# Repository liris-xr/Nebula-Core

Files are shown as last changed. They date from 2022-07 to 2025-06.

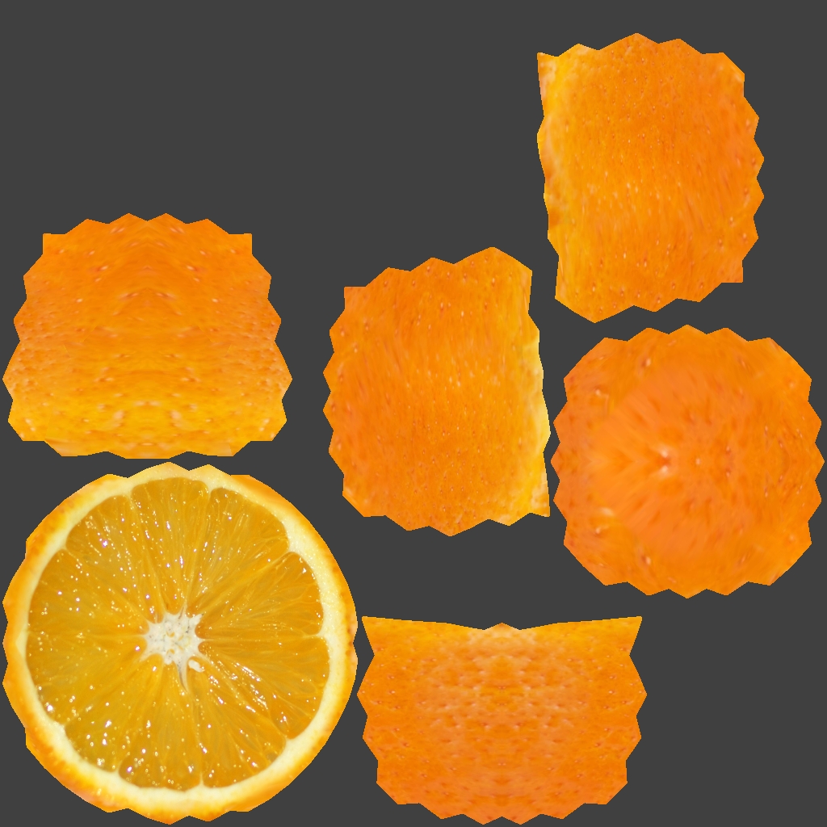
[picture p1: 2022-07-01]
Nebula-UnitySoftware/Assets/3D_Objects/Orange/orange_halb3DC_(null)_color.jpg

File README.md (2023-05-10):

nebula_banner

# Nebula: an affordable open-source and autonomous olfactory display for VR headsets

Charles JAVERLIAT, Pierre-Philippe ELST, Anne-Lise SAIVE, Patrick BAERT, Guillaume LAVOUE.

_Conference on Virtual Reality Software and Technology (VRST), 2022._

[[Paper]](https://hal.science/hal-03838757v1/file/Nebula_VRST_2022%20%281%29.pdf)

## Description 

The impact of olfactory cues on user experience in virtual reality is increasingly studied. However, results are still heterogeneous and existing studies are difficult to replicate, mainly due to a lack of standardized olfactory displays. In that context, we present Nebula, a **_low-cost_** (less than 100€), **_open-source_**, olfactory display capable of diffusing scents at *different diffusion rates* using a nebulization process. Nebula can be used with **PC VR** or **autonomous** head mounted displays, making it easily transportable without any external computer needed.

Nebula can be easily replicated using a 3D printers and some basic electronic skills. On this repo, you will find anything needed in order to build our proposed olfactory display. 

### How does it work?

Nebula create an odorant mist using an **ultrasonic atomizer**, powered by a *pulse width modulated signal* (PWM). As a result, increasing the duty cycle results in an increased rate of diffusion.
This modulation, handled by a micro-controller (we used an Arduino Nano Every) allows Nebula to reach several olfactory intensities.

In addition to the atomizer, we used two fans which are useful to control our air flow. The smallest one, *5VDC 25x25x6mm*, is always active and forces a constant air flow to be able to smell the odor more rapidly after its diffusion and mitigates the pressure drop when enabling the extraction fan. This one is a *12VDC 40x40x20mm*, much stronger, that runs for 2 seconds in order to extract the remaining odorant and thus improve the reactivity of the device.

Nebula is ready to be used with Unity (PC VR built or in editor), using the provided Unity-Package or scripts from the Nebula-UnitySoftware folder.
Furthemore, Nebula works standalone using an Android Archive Library using the provided package on your own built scene. (Tested on a Meta Quest 2)

  ## Repository Structure

  * [Nebula-CAD](https://github.com/Plateforme-VR-ENISE/Nebula-Core/tree/master/Nebula-CAD) contains all STL files (ready to print), a PDF version of the wiring diagram, a list of the necessary components and some printings recommendations.
  * [Nebula-Experiment](https://github.com/Plateforme-VR-ENISE/Nebula-Core/tree/master/Nebula-Experiment) contains results and the unity project used in our experiment described in our paper.
  * [Nebula-Firmware](https://github.com/Plateforme-VR-ENISE/Nebula-Core/tree/master/Nebula-Firmware) contains code for the microcontroller used (Arduino Nano Every).
  * [Nebula-UnitySoftware](https://github.com/Plateforme-VR-ENISE/Nebula-Core/tree/master/Nebula-UnitySoftware) is the Unity project using Nebula in VR including a sample scene with an orange ready to diffuse when approached to the nose !
  
   ## Release content
   
   * ``Nebula-UnityPackage`` Unity Package which includes everything needed to bring Nebula into your project unity. Includes Android Studio project for AAR files generation.
   * ``Nebula-PCSampleScene`` sample scene included in the repository built that countains a ready-to-use application for Nebula.
   * ``Nebula-SampleScene`` same as above but built for Meta Quest 2.

   ## How to install
   
  * Download the lastest ``Nebula.unitypackage`` on the [Release](https://github.com/Plateforme-VR-ENISE/Nebula-Core/releases) section.
  * Open your Unity project or create a new one.
  * Configure .NET 4.x API Compatibility Level **MANDATORY** on your project (*Edit => Project Settings => Player => Other Settings => Api Compatibility Level => .NET 4.x*).
  * Import ``Nebula.unitypackage`` previously downloaded (*Assets => Import Package => Custom Package*) and check *All => Import*.
  * Install OpenXR and XR Interaction Toolkit, you have to install them if you wants to use the provided sample scene (*Windows => Package Manager => Unity registery => Search for Open XR Plugin and XR Interaction Toolkit => Install*).
  * If needed : re-open the project.
   
   ## Contacts
   
   * Pierre-Philippe Elst (Engineer) : pierre-philippe.elst@enise.fr
   * Charles Javerliat (PhD Student) : charles.javerliat@enise.fr
   * Guillaume Lavoué (Professor) : guillaume.lavoue@enise.fr

## Citation

```
@inproceedings{javerliat2022,
  title = {Nebula: An Affordable Open-Source and Autonomous Olfactory Display for VR Headsets},
  author = {JAVERLIAT, Charles and Elst, Pierre-Philippe and Saive, Anne-Lise and Baert, Patrick and Lavou{\'e}, Guillaume},
  booktitle = {Proceedings of the 28th ACM Symposium on Virtual Reality Software and Technology},
  year = {2022},
  month = Nov,
  doi = {10.1145/3562939.3565617},
}
```

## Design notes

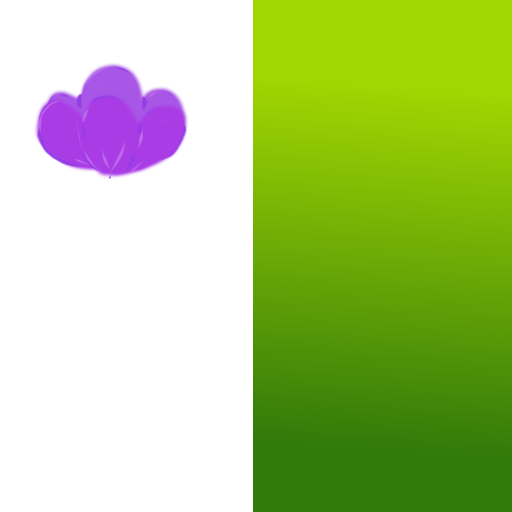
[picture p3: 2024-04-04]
Nebula-UnitySoftware/Assets/3D_Objects/Lavender/plant_lavender_tex.png

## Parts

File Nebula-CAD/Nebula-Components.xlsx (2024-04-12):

Name | Qty | ref | Estimated price - VAT included (€)
Arduino nano every | 1 | ABX00033 | 14
Seed studio - Atomizer | 2 | 101020090 | 22
Sunon - Extraction fan | 1 | MF40100V2-1000U-A99 | 10 | Another option (noiseless) : Noctua NF-A4x10 5V
Sunon - Input fan | 1 | MF25060V2-1000U-A99 | 6
Coton for aroma diffuser diameter 8mm | 1 |  | 8
Transistor NPN | 1 | BD139 | 1
 |  | Total estimated price for Nebula | 61

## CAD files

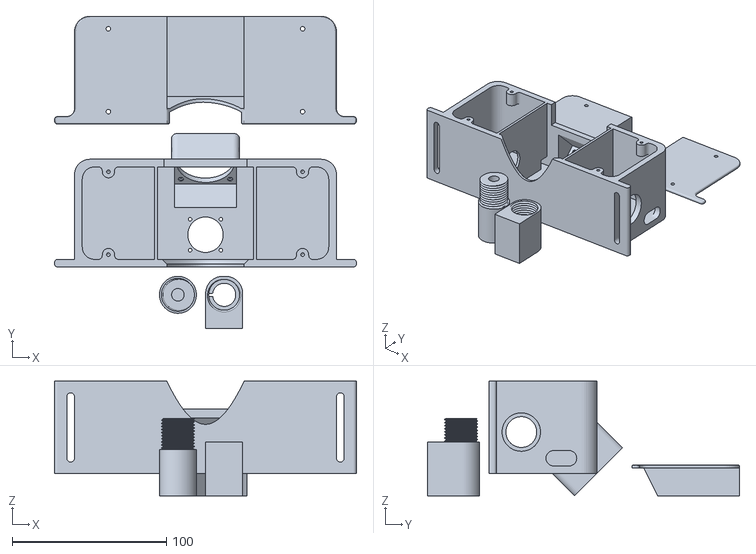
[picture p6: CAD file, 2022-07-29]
Nebula-CAD/Nebula-Complete.stl
196.0 x 202.8 x 74.4

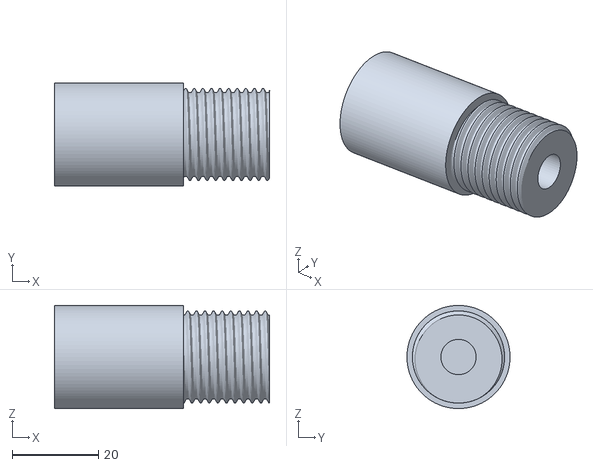
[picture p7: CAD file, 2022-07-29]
Nebula-CAD/Cotton holder.stl
50.0 x 24.0 x 24.0

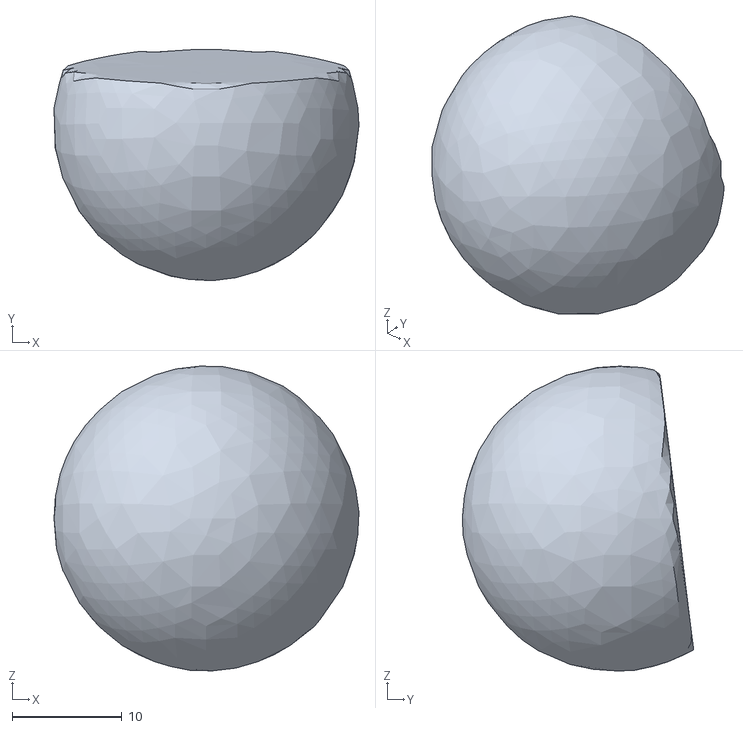
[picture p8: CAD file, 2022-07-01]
Nebula-UnitySoftware/Assets/3D_Objects/Orange/orange.obj
27.8 x 21.1 x 27.8

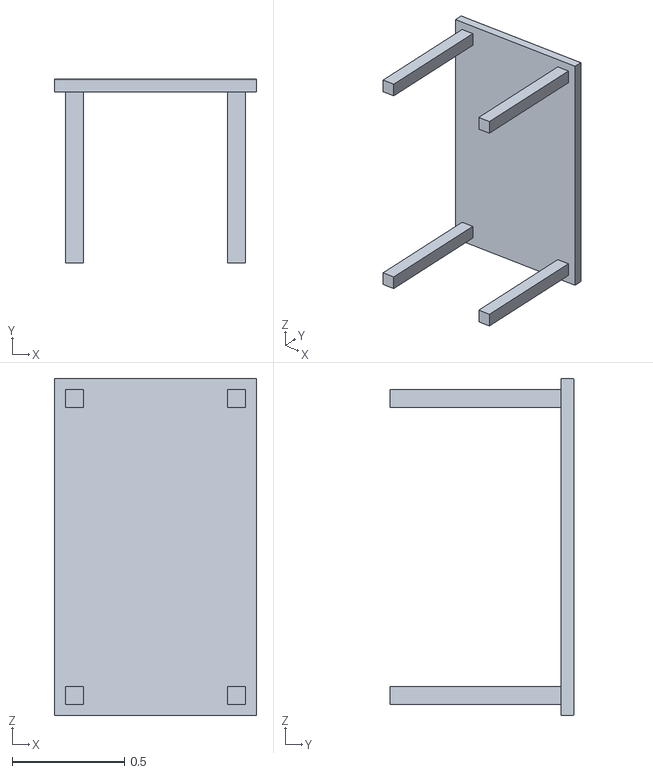
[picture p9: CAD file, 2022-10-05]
Nebula-UnitySoftware/Assets/3D_Objects/Table/Table.obj
0.9 x 0.82 x 1.50

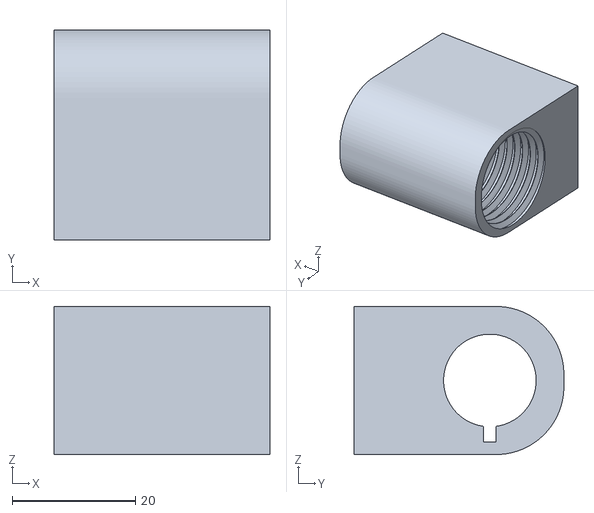
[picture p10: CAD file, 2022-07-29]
Nebula-CAD/Atomizer support.stl
35.0 x 34.0 x 24.0

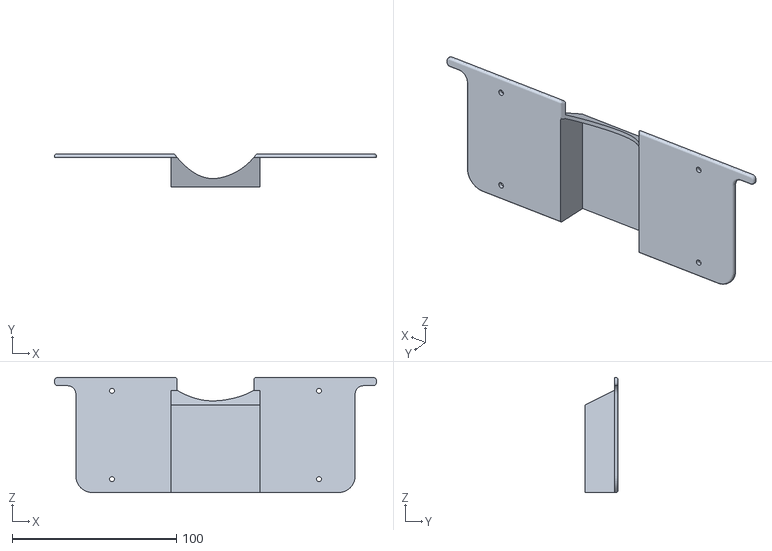
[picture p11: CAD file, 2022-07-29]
Nebula-CAD/Cover.stl
196.0 x 20.0 x 70.0

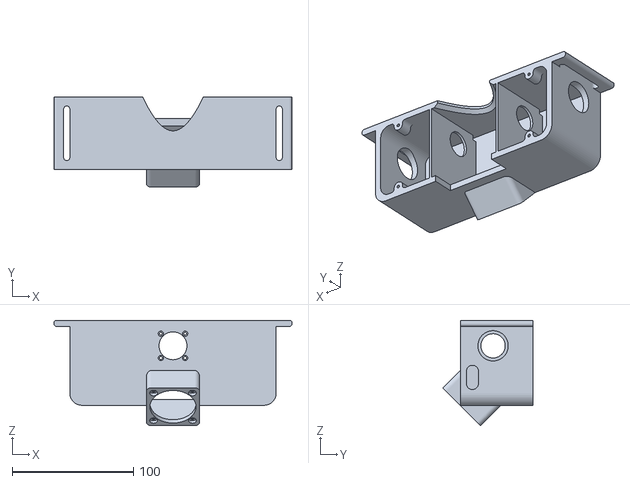
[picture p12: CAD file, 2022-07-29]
Nebula-CAD/Casing.stl
196.0 x 74.4 x 86.8

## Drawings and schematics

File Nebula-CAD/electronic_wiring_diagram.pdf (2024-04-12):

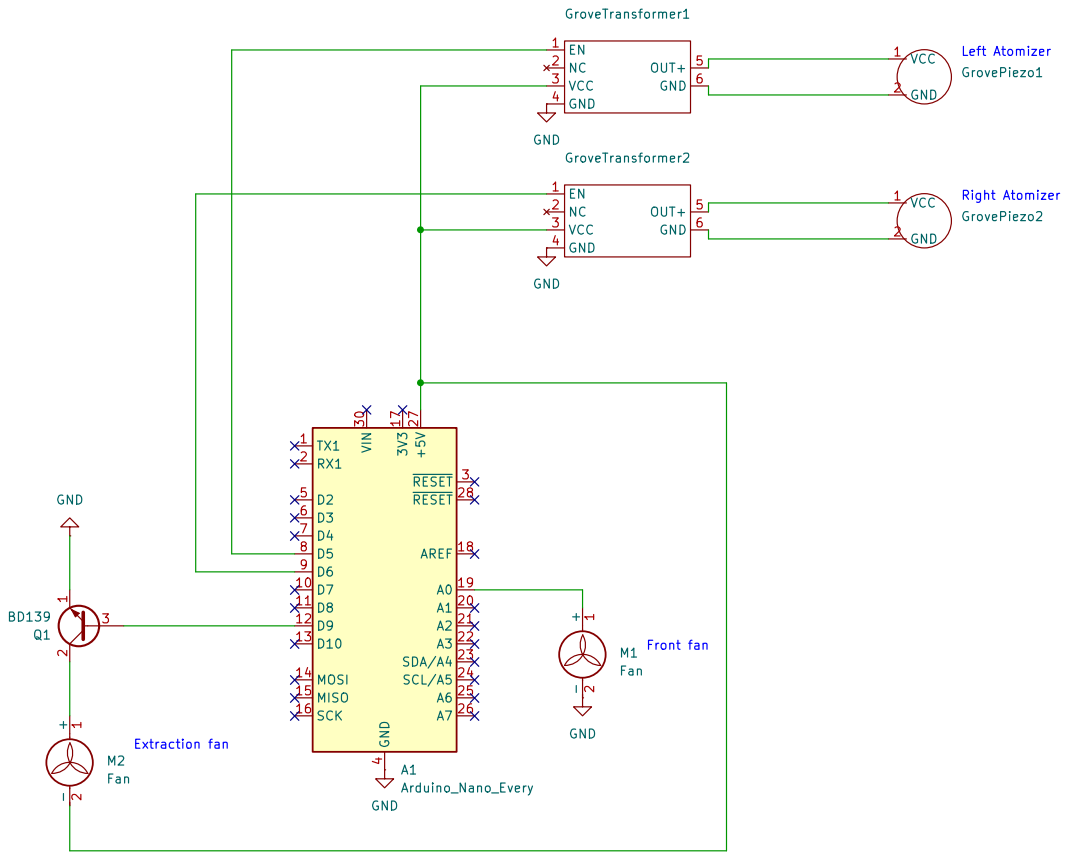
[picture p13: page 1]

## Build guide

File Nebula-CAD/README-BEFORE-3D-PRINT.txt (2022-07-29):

Recommended orientations for printing the components:
- Casing: rotate it 90° around the X axis (generates less supports)
- Cover/Lid: rotate it -90° around X axis
- Atomizer support/cotton holder: rotate it -90° around Y axis

An STL file called "Nebula-Complete" contains all the components with the correct orientation and disposition for printing the full device in a single session.

Recommended printing settings:
- PETG is ideal for humidity resistance, but you can also use PLA. Avoid using ABS which causes skin irritation.
- Enable supports on the build plate.
- 0.2mm layer height with a 0.4mm nozzle. The print doesn't require a lot of precision so feel free to use different settings.
- 20% infill or less
- Use at least one supplementary perimeter to reinforce the strap holder.

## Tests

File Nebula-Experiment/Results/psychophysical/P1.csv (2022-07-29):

Diffusion_Number | Diffusion_Type | Odor_Detected | Odor_Notation | Notation_Time
1 | 2 | 1.703393 | 6 | 4.198804
2 | 1 | 1.737692 | 5 | 6.525969
3 | 0 | -1 | 0 | 2.784424
4 | 2 | 2.004677 | 7 | 18.39915
5 | 0 | -1 | 0 | 3.497033
6 | 2 | 1.759756 | 8 | 5.435187
7 | 1 | 1.848939 | 4 | 2.939597
8 | 0 | -1 | 0 | 2.940423
9 | 1 | 1.269623 | 4 | 2.851298
10 | 0 | -1 | 0 | 5.101238
11 | 2 | 0.9578127 | 7 | 6.259488
12 | 1 | 1.826926 | 3 | 4.143196
13 | 2 | 1.782353 | 5 | 2.160631
14 | 0 | -1 | 0 | 2.316699
15 | 2 | 1.113764 | 6 | 2.338805
16 | 1 | 1.937675 | 2 | 2.094005
17 | 0 | -1 | 0 | 1.871238
18 | 1 | 1.38092 | 3 | 1.914294

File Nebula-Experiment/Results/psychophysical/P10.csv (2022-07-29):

Diffusion_Number | Diffusion_Type | Odor_Detected | Odor_Notation | Notation_Time
1 | 2 | -1 | 8 | 3.620747
2 | 1 | 1.057954 | 5 | 3.063187
3 | 0 | -1 | 0 | 1.926954
4 | 2 | 2.005579 | 8 | 1.680414
5 | 0 | -1 | 0 | 1.84833
6 | 2 | 0.9470239 | 8 | 2.071687
7 | 1 | 1.500624 | 5 | 3.464794
8 | 0 | -1 | 0 | 1.75992
9 | 1 | 1.125526 | 5 | 1.392644
10 | 0 | -1 | 0 | 1.726954
11 | 2 | 1.103103 | 8 | 1.760148
12 | 1 | 1.191909 | 4 | 2.507049
13 | 2 | 0.8689905 | 8 | 1.481762
14 | 0 | -1 | 0 | 1.660323
15 | 2 | 0.7129014 | 8 | 1.915993
16 | 1 | 2.060139 | 5 | 1.681825
17 | 0 | -1 | 0 | 2.005513
18 | 1 | 0.8917294 | 5 | 2.083777

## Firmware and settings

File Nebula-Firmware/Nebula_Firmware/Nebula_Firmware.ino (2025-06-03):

enum Mode
{
  OFF,
  ATOMIZE_LEFT,
  ATOMIZE_RIGHT,
  ATOMIZE_BOTH,
  EXTRACT_AIR,
  FANLESS_ATOMIZE_BOTH,
};

const int ATOMIZER_FAN_PIN = A0;
const int EXTRACTION_FAN_PIN = 9;
const int ATOMIZER_RIGHT_PIN = 6;
const int ATOMIZER_LEFT_PIN = 5;

const int ATOMIZATION_FAN_SPEED = 255;
const int EXTRACTION_FAN_SPEED = 255;

/**
 * @brief When stopping the atomization, the extraction fan runs for a few seconds. This constant determines for how long it will run.
 */
const long EXTRACTION_DURATION = 2000; // ms

/**
 * @brief Square signal definition for the left atomisation
 */
int atomization_period_l = 1000;   // ms
int atomization_duty_cycle_l = 50; // in %
/**
 * @brief Square signal definition for the right atomisation
 */
int atomization_period_r = 1000;   // ms
int atomization_duty_cycle_r = 50; // in %

/**
 * @brief Atomization square signal used for activation.
 * Prevent a long atomization of volatile product to the nose of the participant
 */
bool atomization_sq_sig_l = false;
bool atomization_sq_sig_r = false;

/**
 * @brief Keeps track of when the extraction fan started after stopping atomizing.
 * Used to stop the extraction fan after the duration is expired.
 */
long extraction_fan_start_time = -1;

long atomizations_counter_l = 0;
long atomizations_counter_r = 0;
long last_atomization_update_l = 0;
long last_atomization_update_r = 0;
bool atomize_left = false;
bool atomize_right = false;


enum Mode current_mode = OFF;

void setup()
{
  pinMode(ATOMIZER_LEFT_PIN, OUTPUT);
  pinMode(ATOMIZER_RIGHT_PIN, OUTPUT);
  pinMode(ATOMIZER_FAN_PIN, OUTPUT);
  pinMode(EXTRACTION_FAN_PIN, OUTPUT);
  Serial.begin(115200); // Open COM PORT => WARNING : if NANO EVERY think to enable DTR while opening COM port on Unity!!
  while (!Serial) {
      ;
  }
  Serial.println("Nebula");
}

void update_left_atomization()
{
  long duration_l = atomization_sq_sig_l ? (atomization_duty_cycle_l / 100.0 * atomization_period_l) : (atomization_period_l - atomization_duty_cycle_l / 100.0 * atomization_period_l);


  // Toggle atomisation every period
  if (millis() - last_atomization_update_l >= duration_l)
  {
    last_atomization_update_l = millis();
    atomization_sq_sig_l = !atomization_sq_sig_l;

    if (atomization_sq_sig_l)
    {
      atomizations_counter_l++;
      Serial.print("Number of left atomizations ");
      Serial.println(atomizations_counter_l);
    }
  }
}

void update_right_atomization()
{
  long duration_r = atomization_sq_sig_r ? (atomization_duty_cycle_r / 100.0 * atomization_period_r) : (atomization_period_r - atomization_duty_cycle_r / 100.0 * atomization_period_r);

  // Toggle atomisation every period
  if (millis() - last_atomization_update_r >= duration_r)
  {
    last_atomization_update_r = millis();
    atomization_sq_sig_r = !atomization_sq_sig_r;

    if (atomization_sq_sig_r)
    {
      atomizations_counter_r++;
      Serial.print("Number of right atomizations ");
      Serial.println(atomizations_counter_r);
    }
  }
}


void reset_atomization_counter_l()
{
  atomizations_counter_l = 0;
}

void reset_atomization_counter_r()
{
  atomizations_counter_r = 0;
}

void loop()
{
  String serialReceived;
  char cmdChar;
  String args;

  while (Serial.available() > 0)
  {
    serialReceived = Serial.readStringUntil('\n');
    Serial.print("Received `");
    Serial.print(serialReceived);
    Serial.println("`");
    cmdChar = serialReceived.charAt(0);
    args = serialReceived.substring(1);

    switch (cmdChar)
    {
    case 'L':
      Serial.println("Left atomization");

      if (current_mode == ATOMIZE_RIGHT)
      {
        current_mode = ATOMIZE_BOTH;
      }
      else
      {
        current_mode = ATOMIZE_LEFT;
      }

      break;
    case 'R':
      Serial.println("Right atomization");

      if (current_mode == ATOMIZE_LEFT)
      {
        current_mode = ATOMIZE_BOTH;
      }
      else
      {
        current_mode = ATOMIZE_RIGHT;
      }

      break;
    case 'l':
      Serial.println("Stop left atomization");

      if (current_mode == ATOMIZE_BOTH)
      {
        current_mode = ATOMIZE_RIGHT;
      }
      else if (current_mode == ATOMIZE_LEFT)
      {
        extraction_fan_start_time = millis();
        current_mode = OFF;
      }

      break;
    case 'r':
      Serial.println("Stop right atomization");

      if (current_mode == ATOMIZE_BOTH)
      {
        current_mode = ATOMIZE_LEFT;
      }
      else if (current_mode == ATOMIZE_RIGHT)
      {
        extraction_fan_start_time = millis();
        current_mode = OFF;
      }

      break;
    case 'F':
      Serial.println("Fanless atomization");
      current_mode = FANLESS_ATOMIZE_BOTH;
      break;
    case 'E':
      Serial.println("Extracting air");
      current_mode = EXTRACT_AIR;
      break;
    case 'S':
      Serial.println("Stopped atomization");

      // If previous mode was atomizing, extract air for a few seconds to clean up the air chamber
      if (current_mode == ATOMIZE_LEFT || current_mode == ATOMIZE_RIGHT || current_mode == ATOMIZE_BOTH)
      {
        extraction_fan_start_time = millis();
      }
      current_mode = OFF;
      break;
    case 'C':
      if (sscanf(args.c_str(), "%d;%d", &atomization_period_l, &atomization_duty_cycle_l) == 2)
      {
        Serial.println("Set atomization left configuration to period=" + String(atomization_period_l) + "ms, duty cycle=" + String(atomization_duty_cycle_l) + "%");
      }
      else
      {
        Serial.println("Invalid arguments, expecting command formatted as `CX;Y` with X the atomization period (ms) and Y the duty cycle (%)");
      }
      break;
    case 'D':
      if (sscanf(args.c_str(), "%d;%d", &atomization_period_r, &atomization_duty_cycle_r) == 2)
      {
        Serial.println("Set atomization right configuration to period=" + String(atomization_period_r) + "ms, duty cycle=" + String(atomization_duty_cycle_r) + "%");
      }
      else
      {
        Serial.println("Invalid arguments, expecting command formatted as `DX;Y` with X the atomization period (ms) and Y the duty cycle (%)");
      }
      break;
    default:
      Serial.println("Unknown command");
      break;
    }
  }

  switch (current_mode)
  {
  case ATOMIZE_LEFT:
    update_left_atomization();
    analogWrite(ATOMIZER_FAN_PIN, ATOMIZATION_FAN_SPEED);
    digitalWrite(ATOMIZER_LEFT_PIN, atomization_sq_sig_l ? HIGH : LOW);
    digitalWrite(ATOMIZER_RIGHT_PIN, 0);
    analogWrite(EXTRACTION_FAN_PIN, 0);
    break;
  case ATOMIZE_RIGHT:
    update_right_atomization();
    analogWrite(ATOMIZER_FAN_PIN, ATOMIZATION_FAN_SPEED);
    digitalWrite(ATOMIZER_LEFT_PIN, 0);
    digitalWrite(ATOMIZER_RIGHT_PIN, atomization_sq_sig_r ? HIGH : LOW);
    analogWrite(EXTRACTION_FAN_PIN, 0);
    break;
  case ATOMIZE_BOTH:
    update_left_atomization();
    update_right_atomization();
    analogWrite(ATOMIZER_FAN_PIN, ATOMIZATION_FAN_SPEED);
    digitalWrite(ATOMIZER_LEFT_PIN, atomization_sq_sig_l ? HIGH : LOW);
    digitalWrite(ATOMIZER_RIGHT_PIN, atomization_sq_sig_r ? HIGH : LOW);
    analogWrite(EXTRACTION_FAN_PIN, 0);
    break;
  case EXTRACT_AIR:
    reset_atomization_counter_l();
    reset_atomization_counter_r();
    analogWrite(ATOMIZER_FAN_PIN, ATOMIZATION_FAN_SPEED);
    digitalWrite(ATOMIZER_LEFT_PIN, LOW);
    digitalWrite(ATOMIZER_RIGHT_PIN, LOW);
    analogWrite(EXTRACTION_FAN_PIN, EXTRACTION_FAN_SPEED);
    break;
  case FANLESS_ATOMIZE_BOTH:
    update_left_atomization();
    update_right_atomization();
    analogWrite(ATOMIZER_FAN_PIN, 0);
    digitalWrite(ATOMIZER_LEFT_PIN, HIGH);
    digitalWrite(ATOMIZER_RIGHT_PIN, HIGH);
    analogWrite(EXTRACTION_FAN_PIN, 0);
    break;
  default: // OFF
    reset_atomization_counter_l();
    reset_atomization_counter_r();
    analogWrite(ATOMIZER_FAN_PIN, ATOMIZATION_FAN_SPEED);
    digitalWrite(ATOMIZER_LEFT_PIN, LOW);
    digitalWrite(ATOMIZER_RIGHT_PIN, LOW);

    // extraction_fan_start_time != -1 is used to prevent activating the fan on boot

    if (extraction_fan_start_time != -1 && millis() - extraction_fan_start_time <= EXTRACTION_DURATION)
    {
      analogWrite(EXTRACTION_FAN_PIN, EXTRACTION_FAN_SPEED);
    }
    else
    {
      analogWrite(EXTRACTION_FAN_PIN, 0);
    }

    break;
  }
}

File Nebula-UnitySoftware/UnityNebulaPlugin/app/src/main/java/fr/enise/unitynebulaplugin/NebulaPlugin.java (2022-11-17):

package fr.enise.unitynebulaplugin;

import android.app.Activity;
import android.content.Context;
import android.hardware.usb.UsbDeviceConnection;
import android.hardware.usb.UsbManager;

import com.hoho.android.usbserial.driver.CdcAcmSerialDriver;
import com.hoho.android.usbserial.driver.ProbeTable;
import com.hoho.android.usbserial.driver.UsbSerialDriver;
import com.hoho.android.usbserial.driver.UsbSerialPort;
import com.hoho.android.usbserial.driver.UsbSerialProber;
import com.hoho.android.usbserial.util.SerialInputOutputManager;

import java.io.IOException;
import java.util.List;

public class NebulaPlugin extends Activity {

    public static NebulaPlugin instance;

    private Context context;
    private PluginCallback callback;

    private UsbSerialPort port;

    public NebulaPlugin() {
    }

    public NebulaPlugin(Context context, PluginCallback callback) {
        this.context = context;
        this.callback = callback;
    }

    public void SendMessage(String msg) {
        try {
            port.write(msg.getBytes("US-ASCII"), 9999);
        } catch (IOException e) {
            e.printStackTrace();
        }
    }

    public void InitializeSerialPort() {

        UsbManager manager = (UsbManager) context.getSystemService(Context.USB_SERVICE);

        ProbeTable customTable = new ProbeTable();
        customTable.addProduct(0x2341, 0x0058, CdcAcmSerialDriver.class);

        UsbSerialProber prober = new UsbSerialProber(customTable);
        List<UsbSerialDriver> drivers = prober.findAllDrivers(manager);

        // Open a connection to the first available driver.
        UsbSerialDriver driver = drivers.get(0);
        UsbDeviceConnection connection = manager.openDevice(driver.getDevice());

        UsbSerialPort port = driver.getPorts().get(0); // Most devices have just one port (port 0)
        try {
            port.open(connection);
            port.setParameters(115200, 8, UsbSerialPort.STOPBITS_1, UsbSerialPort.PARITY_NONE);

            this.port = port;

            CustomListener listener = new CustomListener(callback);
            SerialInputOutputManager usbIoManager = new SerialInputOutputManager(port, listener);
            usbIoManager.start();
        } catch (IOException e) {
            e.printStackTrace();
        }
    }

    public static NebulaPlugin InitializePlugin(Context context, PluginCallback callback) {
        instance = new NebulaPlugin(context, callback);
        instance.InitializeSerialPort();
        return instance;
    }

}

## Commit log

2022-07-05 Project reorganized + added MAO firmware
    [ZAHA LIGHT white pendant Simplified.obj, sdsdfs.unity_1.obj]
2022-07-26 Project renamed + GUI added
    [ZAHA LIGHT white pendant Simplified.obj, sdsdfs.unity_1.obj]
2022-07-27 Updated scripts with conditionnal compilation
    Scripts are now multiplatform friendly
    _Android while standalone
    _Android while using editor
    _Windows standalone
    _Windows while using editor (with GUI available on this case only for the moment)
    Renamed scripts for better overall understanding
    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
2022-07-29 Release commit
    Including STL files for 3D printing
    Several minor changes
    [Atomizer support.stl, Casing.stl, Cotton holder.stl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]
2022-07-29 Added supplementary material
    Nebula psychophysical experiment unity project
    Results from experiments
    Electronic wiring diagram
    [P1.csv, P10.csv, P11.csv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]
2022-10-05 Created new sample scene
    + added the posibility to reset smelling props (QoL improvement while demonstrating our sample scene) when it's falling on the ground
    + fixed various typos
    + code clean-up
    [Table.obj, ZAHA LIGHT white pendant Simplified.obj, orange.obj]
2022-10-06 Bug fixes
    + added SteamVR controller profile
    + now correctly reset forces when the orange is falling on the ground on the sample scene
    + scalled the table correctly on the sample scene
2022-11-04 bug fixes
    button now stops atomization when pressed
    currentDutyCycle var now correcly return to 0 when there is no diffusion
    typos corrected
    change duty cycle relation between distance
    renamed some variables
2022-11-05 Whole project upgrade
    [Table.obj, orange.obj]
2024-04-12 Corrected electronic wiring diagram
2024-04-12 Updated components
    Updated list for a better input fan and an option for the extraction fan
    [Nebula-Components.xlsx]
2025-06-03 fixed dual atomization
    updated firmware
    [Nebula_Firmware.ino]
